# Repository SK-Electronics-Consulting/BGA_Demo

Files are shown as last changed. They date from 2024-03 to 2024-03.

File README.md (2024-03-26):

# BGA Demo

This project is a sandbox-type project with the intention of finding the limitations
and edges of using cheap PCB manufucturing for BGA chips.

Cheap PCB manufacturing in this case are the vendors who provide very inexpensive
PCB fabrication and assembly services, such as JLCPCB and PCBWay.  

The specific goals of this project are:

1. Determine what manufacturing capability is needed for each example BGA. This includes
trace width and spacing, using blind/buried vias, and so on.  
1. Document the costs and turn around times. This may or may not include using
alternates or already in-stock parts (JLC, I'm looking at you!).

## Assumptions

1. Through hole components will be not populated.
1. Only top layer will be populated. Placing components on both sides increases cost. The types of projects that would require BGAs and double sided placement, would also really require a deeper CM relationship than what JLC/PCBWay provide.

## Scope

Items that are out of scope for this project:

1. Unrelated costs and delays, such as delays due to Lunar New Year or parts that are exceptionally difficult to source.

## Versions

### [STM32L431CCY](https://www.st.com/resource/en/datasheet/stm32l431cc.pdf)

This is a WLCSP49 package, 3.1x3.1mm, 0.4mm pitch chip.

#### March 2024 order

* 4-layer board, non-HDI.
* Trace/Space: 0.076mm (0.003")
* Vias 0.25mm w/ 0.15mm hole
* Via in pad was needed
* Smallest Passive is 0402.
* Ordered from JLCPCB on 2024/03/19, delivered on 2024/03/28
* Cost: $255.01
* Mostly just a demo board for the chip. Included a CAN PHY as that's been needed for some projects recently.
* Omitted all through hole components.
* TODO: Actually make the board based on ST's recommendation.  (I rushed ordering it, so I might have missed something crucial and this board be a dud.)
* TODO: Add a Tag-Connect to avoid the 10-pin connector.
* TODO: (Not related to this experiment) Add a 24V to 3.3V SMPS.
* TODO: Try making this with 0.0035" traces, as that seems to be a cost-adder-threshold for JLC.
* Not all balls were able to be exposed in the fanout.  In this design 8 of 49 were left unconnected. A couple of those 8 could easily be brought out, but definitely not all 49 in this fab. See (#learnings) #1.

## Learnings

1. To get a 7x7 grid out completely, you would need blind vias at a minimum, if not a 2+N(+2) stackup. This is because if you look at the 4th (middle) row, you'd fan out this way: `[Top, Blind to In1, Through to In2 or Bottom, (TBD??), Through to In2 or Bottom, Blind to In1, Top]`

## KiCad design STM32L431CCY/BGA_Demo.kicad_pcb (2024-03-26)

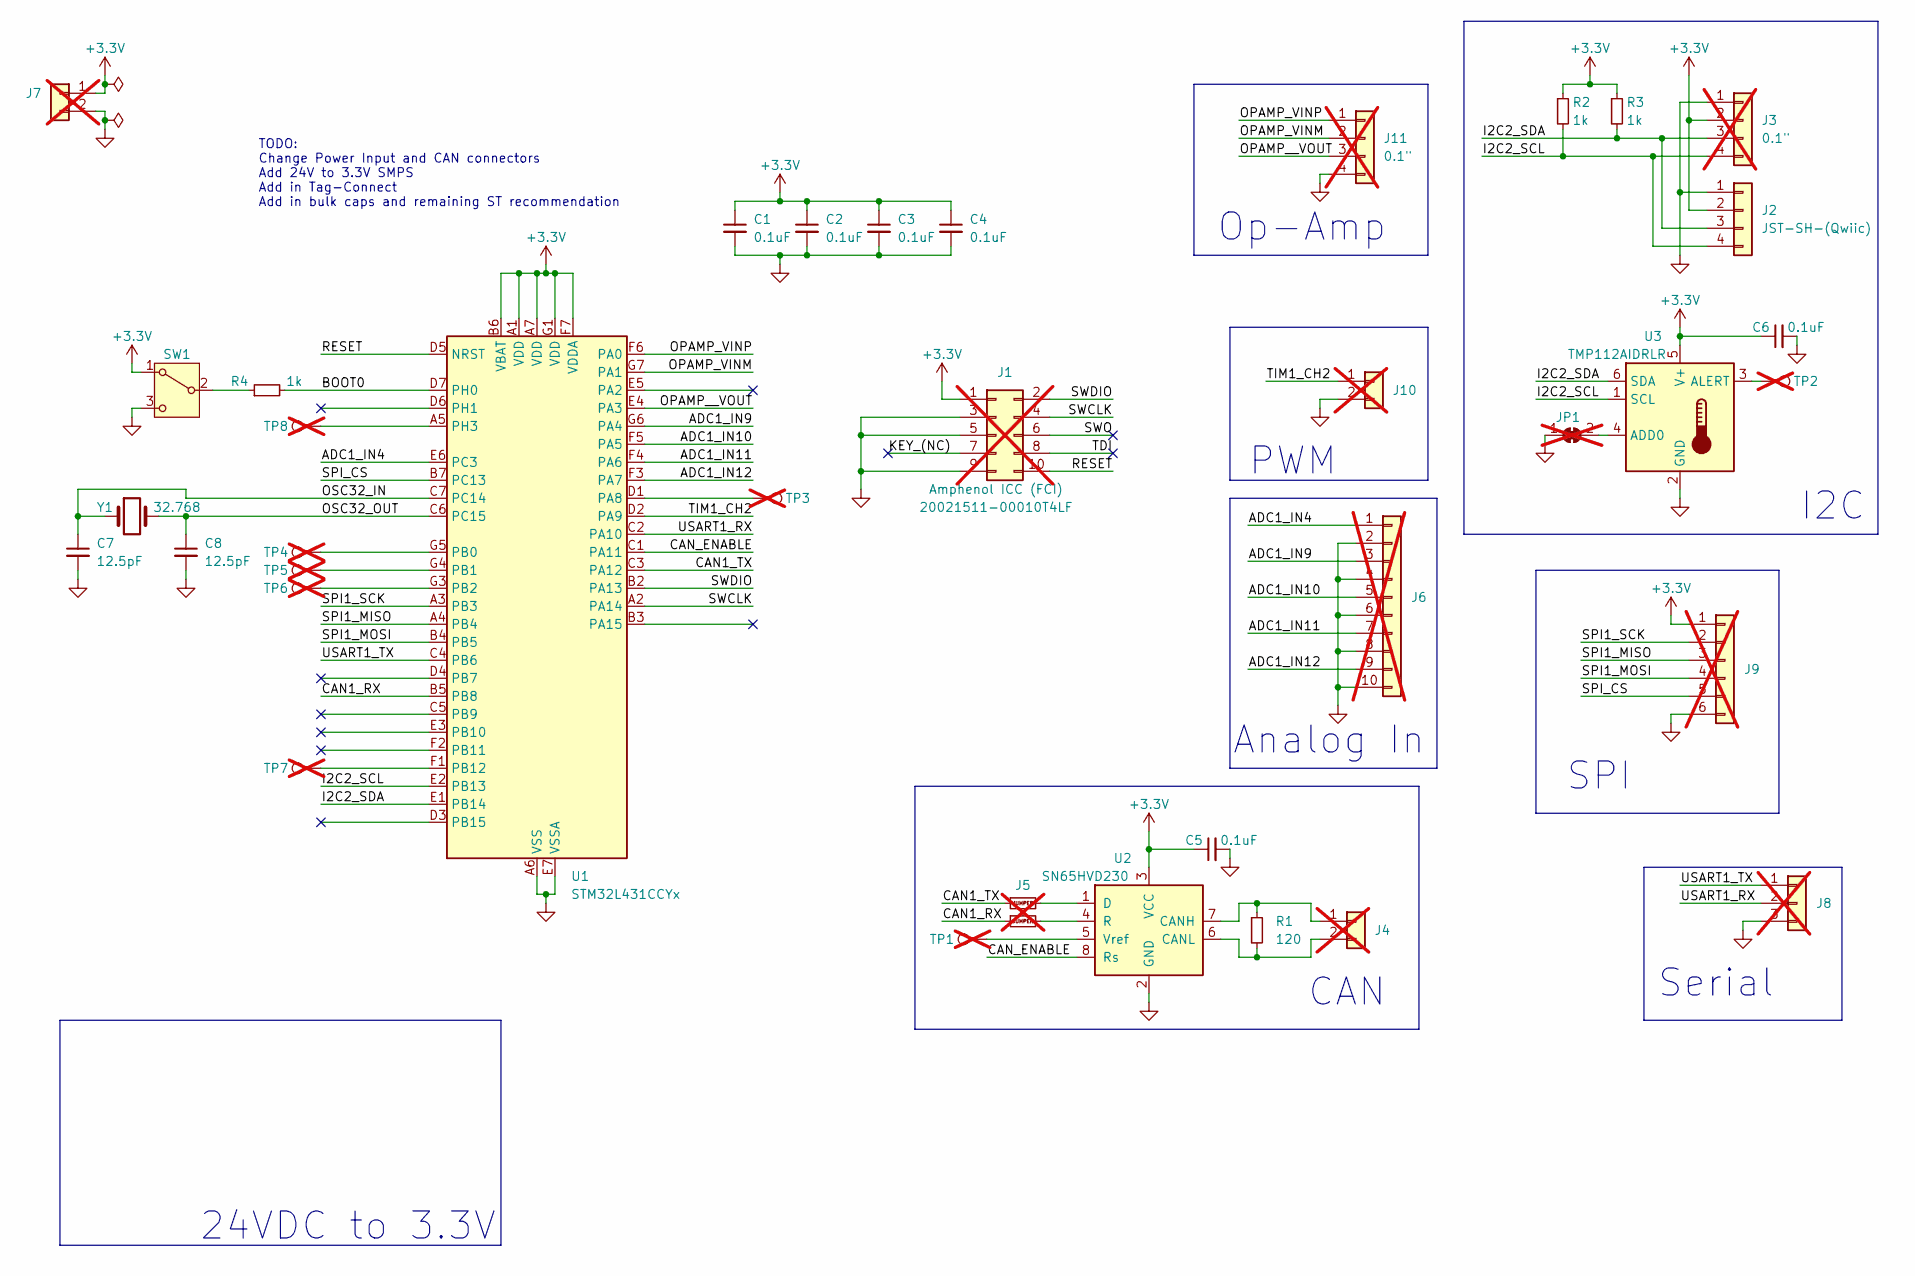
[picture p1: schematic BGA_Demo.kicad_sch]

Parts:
C1, C2, C3, C4, C5, C6: 0.1uF; C_0402_1005Metric_Pad0.74x0.62mm_HandSolder; Part Num CC0402KRX7R7BB104; LCSC Part # C60474
C7, C8: 12.5pF; C_0402_1005Metric; Part Num CC0402JRNPO9BN120; LCSC Part # C106201
J1: Conn_02x05_Odd_Even; PinHeader_2x05_P1.27mm_Vertical; Part Num 20021511-00010T4LF; not fitted
J2: JST-SH-(Qwiic); JST_SH_SM04B-SRSS-TB_1x04-1MP_P1.00mm_Horizontal; Part Num SM04B-SRSS-TB(LF)(SN); LCSC Part # C160404
J3, J11: 0.1"; PinHeader_1x04_P2.54mm_Vertical; not fitted
J4, J7, J10: Conn_01x02; PinHeader_1x02_P2.54mm_Vertical; not fitted
J5: RX_TX_Swap; RX_TX_SWAP_0402; not fitted
J6: Conn_01x10; PinHeader_1x10_P2.54mm_Vertical; not fitted
J8: Conn_01x03; PinHeader_1x03_P2.54mm_Vertical; not fitted
J9: Conn_01x06; PinHeader_1x06_P2.54mm_Vertical; not fitted
JP1: SolderJumper_2_Bridged; SolderJumper-2_P1.3mm_Bridged_Pad1.0x1.5mm; not fitted
R1: 120; R_0603_1608Metric_Pad0.98x0.95mm_HandSolder; Part Num AC0603FR-07120RL; LCSC Part # C125925
R2, R3, R4: 1k; R_0402_1005Metric; Part Num RC0402FR-071KL; LCSC Part # C106235
SW1: SW_SPDT; SW_SPDT_CK_JS102011SAQN; Part Num JS102011SAQN; LCSC C221660
TP1: TestPoint; TestPoint_Keystone_5010-5014_Multipurpose; not fitted
TP2, TP3, TP4, TP5, TP6, TP7, TP8: TestPoint; TestPoint_Pad_1.0x1.0mm; not fitted
U1: STM32L431CCYx; ST_WLCSP-49_Die435
U2: SN65HVD230; SOIC-8_3.9x4.9mm_P1.27mm; Part Num SN65HVD230DR; LCSC Part # C12084
U3: TMP112AIDRLR; SOT-563; LCSC C28927
Y1: 32.768; Crystal_SMD_3215-2Pin_3.2x1.5mm; Part Num H31003271C2070CY; LCSC C5361379

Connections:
+3.3V: C1.1, C2.1, C3.1, C4.1, C5.1, C6.1, J1.1, J2.2, J3.2, J7.1, J9.1, R2.1, R3.1, SW1.1 (A), U1.A1 (VDD), U1.A7 (VDD), U1.B6 (VBAT), U1.F7 (VDDA), U1.G1 (VDD), U2.3 (VCC), U3.5 (V+)
/ADC1_IN4: J6.1, U1.E6 (PC3)
/ADC1_IN9: J6.3, U1.G6 (PA4)
/ADC1_IN10: J6.5, U1.F5 (PA5)
/ADC1_IN11: J6.7, U1.F4 (PA6)
/ADC1_IN12: J6.9, U1.F3 (PA7)
/BOOT0: R4.2, U1.D7 (PH0)
/CAN1_RX: J5.1B, U1.B5 (PB8)
/CAN1_TX: J5.1A, U1.C3 (PA12)
/CAN_ENABLE: U1.C1 (PA11), U2.8 (Rs)
/I2C2_SCL: J2.4, J3.4, R2.2, U1.E2 (PB13), U3.1 (SCL)
/I2C2_SDA: J2.3, J3.3, R3.2, U1.E1 (PB14), U3.6 (SDA)
/KEY_(NC): J1.7
/OPAMP_VINM: J11.2, U1.G7 (PA1)
/OPAMP_VINP: J11.1, U1.F6 (PA0)
/OPAMP__VOUT: J11.3, U1.E4 (PA3)
/OSC32_IN: C7.1, U1.C7 (PC14), Y1.1
/OSC32_OUT: C8.1, U1.C6 (PC15), Y1.2
/RESET: J1.10, U1.D5 (NRST)
/SPI1_MISO: J9.3, U1.A4 (PB4)
/SPI1_MOSI: J9.4, U1.B4 (PB5)
/SPI1_SCK: J9.2, U1.A3 (PB3)
/SPI_CS: J9.5, U1.B7 (PC13)
/SWCLK: J1.4, U1.A2 (PA14)
/SWDIO: J1.2, U1.B2 (PA13)
/SWO: J1.6
/TDI: J1.8
/TIM1_CH2: J10.1, U1.D2 (PA9)
/USART1_RX: J8.2, U1.C2 (PA10)
/USART1_TX: J8.1, U1.C4 (PB6)
GND: C1.2, C2.2, C3.2, C4.2, C5.2, C6.2, C7.2, C8.2, J1.3, J1.5, J1.9, J2.1, J3.1, J6.2, J6.4, J6.6, J6.8, J6.10, J7.2, J8.3, J9.6, J10.2, J11.4, JP1.1 (A), SW1.3 (C), U1.A6 (VSS), U1.B1 (VSS), U1.E7 (VSSA), U1.G2 (VSS), U2.2 (GND), U3.2 (GND)
unnamed: J4.1, R1.1, U2.7 (CANH)
unnamed: J4.2, R1.2, U2.6 (CANL)
unnamed: JP1.2 (B), U3.4 (ADD0)
unnamed: R4.1, SW1.2 (B)
unnamed: TP3.1, U1.D1 (PA8)
unnamed: TP4.1, U1.G5 (PB0)
unnamed: TP5.1, U1.G4 (PB1)
unnamed: TP6.1, U1.G3 (PB2)
unnamed: TP7.1, U1.F1 (PB12)
unnamed: TP8.1, U1.A5 (PH3)
unnamed: J5.2A, U2.1 (D)
unnamed: J5.2B, U2.4 (R)
unnamed: TP1.1, U2.5 (Vref)
unnamed: TP2.1, U3.3 (ALERT)

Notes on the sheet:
TODO: Change Power Input and CAN connectors Add 24V to 3.3V SMPS Add in Tag-Connect Add in bulk caps and remaining ST recommendation
24VDC to 3.3V
PWM
Analog In
Op-Amp
SPI
CAN
I2C
Serial

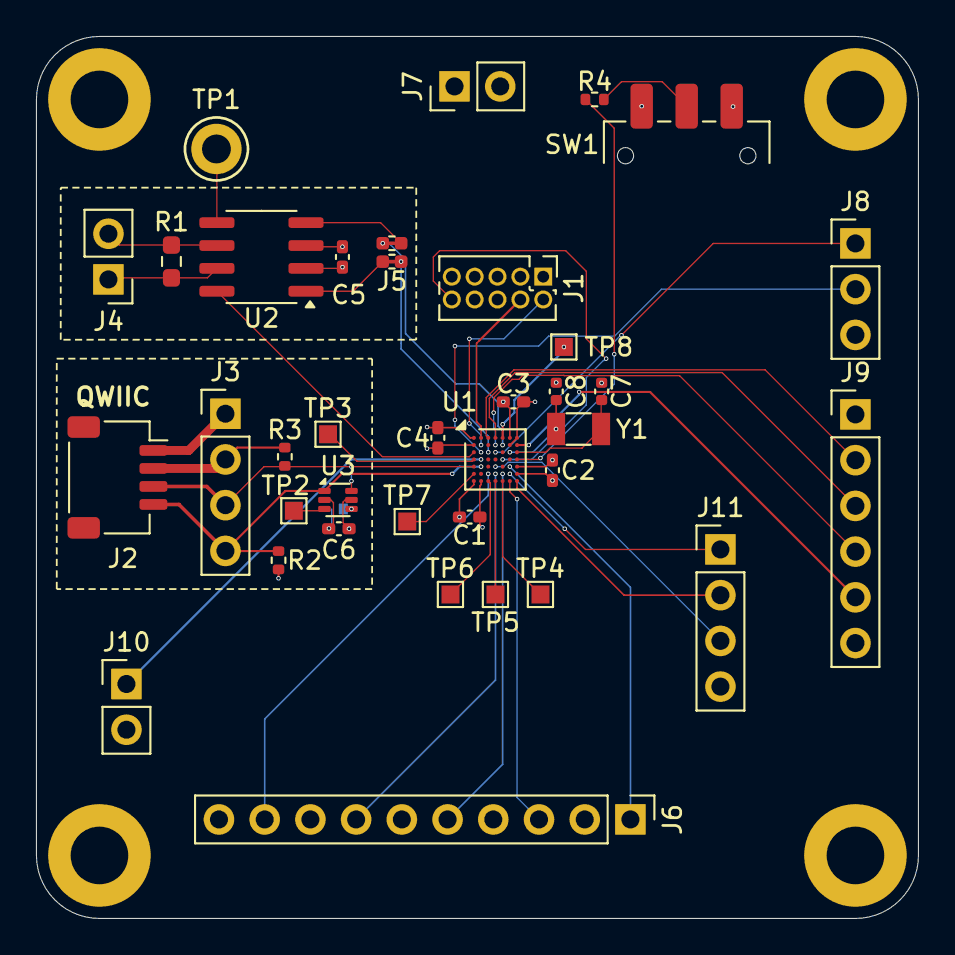
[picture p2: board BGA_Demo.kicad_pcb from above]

Board: 4 copper layers, 49.0 x 49.0 mm, 37 parts (1 on the bottom side), 42 nets.
